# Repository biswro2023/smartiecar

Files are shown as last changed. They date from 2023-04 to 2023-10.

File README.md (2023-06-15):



Future Engineers - Smart Riders 
====

## Inhalt

* Der Ordner [`Programmcode`](https://github.com/biswro2023/smartiecar/tree/master/Programmcode) enthält den kompletten Programmcode, der für das Roboterauto verwendet wird.
* Im Ordner [`Roboterauto`](https://github.com/biswro2023/smartiecar/tree/master/Roboterauto) befinden sich sechs Fotos Von unserem Roboterauto aus allen Perspektiven
* Im Ordner [`Technische Zeichnungen`](https://github.com/biswro2023/smartiecar/tree/master/Technische%20Zeichnungen) sind Zeichnungen von Komponenten des Roboterautos oder dem gesamten Roboterauto abgelegt.
* Der Ordner [`Video`](https://github.com/biswro2023/smartiecar/blob/master/Video/video.md) beinhaltet die Datei "video.md", die mit zwei Links zu den Youtube-Videos weiterleitet. Das Video zeigt das Roboterauto beim Absolvieren des Spielfeldes in beiden Rennen.
* Der Ordner [`Unser Team`](https://github.com/biswro2023/smartiecar/tree/master/Unser%20Team) hat ein Bild von unserem Team zu Beginn und ein aktuelles sowie eine kurze Beschreibung über uns.

## Einleitung

Nach dem Ende unseres vorherigen FLL Wettbewerbes wollten wir erneut an einem Projekt arbeiten. Wir haben uns dazu entschieden in der WRO mitzuspielen und uns die verschiedenen Kategorien angeschaut. Ein anderes Team an unserer Schule hatte bereits an einem Future Engineers Projekt gearbeitet. Das hat uns sehr interessiert und wir haben uns entschieden ebenfalls in dieser Kategorie zu spielen. Selbstfahrende Autos sind generell schon ein sehr interessantes und aktuelles Thema, das in der heutigen Zeit immer wichtiger wird. Zu Beginn hörten sich die Aufgaben, wie Runden auf einer Matte zu fahren, deutlich leichter an, als sie tatsäclich waren. Schwierigkeiten machten oft Kleinigkeiten, wie Messungenauigkeiten oder dreckige Reifen.
Im Laufe der Zeit haben wir viel Arbeit in die Fehlervermeidung und Vorbeugung gesteckt. Wir haben viele Sicherheitsmechanismen eigebaut, bis das Auto in fast allen Situationen gut gefahren ist. Insgesamt aben wir jetzt deutlich besser verstanden, wie schwer die Entwicklung und Produktion von selbstfahrenden Autos eigentlich ist.

Details zum Entwicklungsprozess von Chassis und Elektronik des Autos Beschreiben wir in => [`RoboterAuto-Readme.md`](https://github.com/biswro2023/smartiecar/blob/master/Roboterauto/README.md)

Das Programm und Informationen zur Steuerlogik befinden sich in => [`Programmcode`](https://github.com/biswro2023/smartiecar/tree/master/Programmcode)

Unser Auto in Aktion ist zu sehen in =>  [`Video-Readme.md`](https://github.com/biswro2023/smartiecar/blob/master/Video/video.md)

Kino Shot

Quellen:

https://totemmaker.net/  (Auto/Rahmen)

https://de.wikipedia.org/wiki/Lenkung#Achsschenkellenkung    (Lenkgeometrie)

https://funduino.de/  (Programmierbeispiele etc.)

https://fritzing.org/   (Schaltpläne)

Coaching mit Team Leoneers 

https://www.arduino.cc/    (Programm etc.)

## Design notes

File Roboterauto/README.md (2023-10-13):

Roboterauto
====

Prozess:

Wir haben uns für die Konstruktion des Autos für das Totem Maker Bausystem (siehe Quellen) entschieden. Das Auto, dass auf der Website vorgeschlagen ist, ist zu groß und hat einen nicht erlaubten Antrieb. Deswegen haben wir unser Chassis neu konstruiert und nur teilweise auf die Anleitung zurückgegriffen.
Zu Beginn haben wir die ersten Schritte, der im Totem Maker Bausystem vorgeschlagenem Bauanleitung befolgt, um eine stabile Vorderachse zu erhalten.
Da das Auto, das die Anleitung beschreibt zu breit ist, mussten wir die Vorderachse kürzen. So überschreitet unser Auto die vorgegebenen Maße nicht.




Die Vorderachse beinhalted 3D gedruckte Teile, die jedoch von Totem Maker gedruckt und beigelegt wurden.
Die 3D gedruckten Teile, der Vorderachse stammen aus der STL-Libary von Totem Maker.
Zu dem Zeitpunkt haben wir die standard Reifen des Totem Maker Bausystems verwendet. 
Danach haben wir eine Bodenplatte aus 4mm dickem Kunststoff geschnitten und an die Vorderachse geschraubt.
Wir haben eine 4mm Platte genommen, da wir vermuteten, dass eine Platte, die nur 2mm dick ist, schnell brechen würde.
Um die Position der Hinterachse zu bestimmen haben wir mit Hilfe einer Bauzeichnung  unserer Bodenplatte ein Lenkdreieck gezeichnet.

Bodenplatte-1

Die Hinterachse und den Motor haben wir dann auf die Bodenplatte geschraubt.
Der Motor ist mit einer 1:1 Überetzung mit zwei Zahnrädern an der Hinterachse angeschlossen.
Anschließend haben wir uns überlegt und ausprobiert, wie wir die elektronischen Bauteile auf dem Auto befestigen. 
Der Motorkontroller so wie unseren Hauptstromschalter haben wir auch auf der Bodenplatte befestigt. 
Der Lipo-Akku liegt auf dem Rahmen unseres Autos.

Bei den ersten Testfahrten ist uns aufgefallen, dass unsere Reifen, die wir aus dem Totem Maker Bausystem genommen haben, zu groß sind und am 
Rahmen schleifen. Die zweiten Reifen aus dem Funduino Bauset waren kleiner und härter, aber sie übersteuerten oft wenn das Auto zu sehr einlenk.
Das Problem war dadurch teilweise gelöst.
Jetzt und Final verwenden wir Reifen, die weicher sind und kein Profil besitzen, wodurch der Bodenkontakt maximiert wird.
Diese Reifen haben wir aus einem Modellbauladen erhalten.

image0 (1)

Damit wir den Arduino auf dem Auto befestigen können, haben wir zuerst eine vorgeschnitte Kunststoffplatte aus dem Funduino Bauset benutzt. 
Diese ist aber leider gebrochen, weshalb wir eine neue Platte aus enem dickerem Kunststoff schneiden mussten.
Der Aurduino ist nun mit Kunststoff Abständen an dieser Platte fest geschraubt.

Links

Als der Ardunio befestigt war konnten wir schließlich Programme für das Auto schreiben und ausprobieren.
Um auch Feedback zu Problemen oder Erfolgen zu erhalten, haben wir ein LCD-Monitor auf dem Auto befestigt.
Dieser Monitor gibt sowohl am Anfang des Programmes Informationen über die Sensoren als Text, als auch durch den verschieden farbigen Hintergrund Informationen über den Aktuellen Status des Programmes.

Als wir den Monitor zum erstem mal angeschlossen hatten, konten wir nichts erkennen. der Monitor zeigte kein Text oder Farbe.
Wir fanden herraus, dass der Monitor 5 Volt benötigt, wir ihn aber nur 4.7 Volt angeschlossen hatten.
Deshalb haben wir sowohl für die Stromversorgung des LCD-Monitors als auch für die Stromversorgungs unseres Lenkservos eine extra Stromversorgungsleiste eingebaut

237098416-ef6eb164-e023-4361-834d-cc200a337ebe

Oben auf unserem Auto haben wir neben dem LCD-Monitor und der Stromleiste außerdem auch noch den Button für den Start und den Gyro für die Kurven montiert.
Zu Beginn hatten wir einen anderen größeren Button verwendet. Weil der jedoch einen großen Wiederstandhatte, der das Auto beim drücken mit nach unten drückte, und weil er nicht gut erreichbar montiert war,
haben wir den Button ausgetauscht zu dem Button, den wir jetzt verwenden.
Anschließend haben wir uns um das Kabelmanagement gekümmert. Wir haben die wichtigen Anschlüsse des Hauptsromsystems an der Außenseite mit schnell verschlüssen befestigt, da mit wir das Auto schnell warten 
und reparieren können.

Bild SV

Damit wir die Kurven gut fahren können haben wir außerdem neben dem Button ein Gyroskop eingebaut.
Das Gyroskop hilft uns genaue Kurven mit immer gleich bleibendem Winkel zu fahren.
Für das Hindernissrennen wollten wir anschließend auch eine Kamera an unserem Auto montieren.
Wir hatten zwei verschiedene Kameras zu auswahl: Die HHUSKYLENS und die PIXY CAM 2.

image0 (1)

Wir haben beide Kameras ausprobiert und sind schließlich bei der PIXY CAM geblieben.
Obwohl die HHUSKYLENS die Hindernisse und Linien gut erkennen konnte, hat die PIXY CAM ein größeres Blickfeld und mehr kofiguratiosns Möglichkeiten in dem zugehörigem Programm. Dadurch können wir viel mehr abstimmen und Feintuning betreiben.

Für die Energeiversorgung, die wir uns schon zu Beginn zurechtgelegt haben, benutzen wir eine 11,5 Volt Lipo Batterie.
Die Batterie gibt zwischen 9,4 und 12,4 Volt aus. Da der Motor 12 Volt benötigt und der zugehörige Motortreiber gleichzeitig auch noch 1,4 Volt bezieht, haben wir einen Step Up Converter einegbaut, der die Spannung auf 13.4 Volt erhöht.
So erhält der Motor immer die richtige Spannung. Da die eine Hälfte des Stroms zu dem Motor geleitet wird, wird die andere Hälfte zu einem Step Down Converter geleitet. Dieser reduziert die Spannung auf 5 Volt. Das ist wichtig, weil der Arduino nicht mit dem 13,4 Volt umgehen kann.
Diese 5 Volt leiten wir anschließend in einen USB-Hub der gleichzeitig auch als Voltmeter dient.
Aus diesem USB-Hub geht eine Stromleitung dierekt zu dem Arduino und die andere zur Hauptstromleiste. Diese mussten wir installieren, weil 
die 5 Volt ausgabe des Arduinos nicht genau 5 Volt ausgibt. Sowohl der LCD Monitor als auch der Lenkservo benötigen nämlich mindestens 5 Volt.

238084341-53173d58-f437-4e53-b33c-3225937c58c4

Nach dem ersten Wettbewerb in Chemitzt haben wir beschlossen die Halterung für die Kamera und die Ultraschallsensoren umzubauen.
Die alte Halterung hat sich schnell gelöst und verschoben. Nun ist die neu Halterung fest an den Rahmen des Autos befestigt.



Außerde haben wir für die Ultraschallsensoren neue Halterungen verwendet, damit sie stabiler sitzten und einfacher zu montieren sind.
Durch diese neuen Halterungen der Sensoren, waren diese jedoch leicht nach oben geneigt, was manchmal zu fehlmessungen führte.
Deshalb haben wir Kabelbinder verwendet, um die Sensoren zusammen zu binden und unten zu halten.
Da der Farbsensor, den wir zuvor an unserem Auto befestigt hatten die Farben des Spielfeldes immer wieder falsch erkannte,
haben wir uns dafür entschieden diesen zu entfernen, da er so keien Nutzen für uns hat.

Zusätzlich haben wir versucht ein neues Getriebe in das Auto einzubauen (zuvor 1:1). Wir wollten eine größere Übersetzung der Zahnräder dazu verwenden
unser Auto langsam fahren zu lassen, ohne, dass es stecken bleibt. Den zuvor konnten wir dies nur verhindern, indem wir schneller fuhren,
was das ganze Rennen ungenauer machte.Schließlich hat aber das neue Getriebe mehr neue Probleme hervorgebracht als alte gelöst.



Während der vielen Testrunden die wir gefahren sind ist neben Sensoren und Arduinos auch unser Lenkserveo einmal kaputt gegangen.
Die Kontruktionsweise des Autos behinderte den Austausch etwas, jedoch haben wir die Gelegenheit genutz gleichzeitig auch noch Teile Auszutauschen, an
die man sonst nicht so leicht dran kommt.



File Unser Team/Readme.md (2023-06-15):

Team Beschreibung
===
Unser Team besteht aus drei Jungs: Noah, Nezar und Lucius. Gemeinsam repräsentieren wir stolz die GSG Lünen und haben uns den Teamnamen "Smart Riders" gegeben. Wir gehen alle in die 10. Klasse, und es ist das erste Mal, dass wir an der WRO teilnehmen. Unser erstes Roboterprojekt war die Teilnahme an der FLL.

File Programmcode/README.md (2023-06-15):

Programmcode
====

Dieser Ordner enthält sämtlichen Programmcode, der in dem Roboterauto zum Einsatz kommt.
Zudem auch Programme zum testen ob diverse sensoren funktionieren. Zudem Backup Codes Im Fall von einer Änderung.

· [`Eröffnungsrennen`](https://github.com/biswro2023/smartiecar/tree/master/Programmcode/main_hinderniss_V01)

· [`Hindernissrennen`](https://github.com/biswro2023/smartiecar/tree/master/Programmcode/main_hinderniss_V01)

· [`Testprogramme`](https://github.com/biswro2023/smartiecar/tree/master/Programmcode/Test%20Programme)

· [`backup codes`](https://github.com/biswro2023/smartiecar/tree/master/Programmcode/alte_versionen/backup%20codes)

Allgemeines
===
Zuerst haben wir kleine kleine Testprogramme für die Bewegungen und Sensoren des Autos geschrieben. Dabei Haben wir uns an Beispielen von Funduino.de orientiert und Beispielprogramme der Sensorhersteller benutzt. Unsere neu geschriebenen Programme haben wir mit einer Versionsnummer im Namen gekennzeichnet. Zum Beispiel heisst die erste Version `main_OH_V1.ino`. Unsere Hauptdatei endet mit `.ino` und die untergeteilten Dateien mit `.h` 

Programmaufbau
===
Als erstes haben wir alle erforderlichen Bibliotheken für den Roboter und die einzelnen Komponenten hinzugefügt. Anschließend haben wir globale Variablen sowie unsere eigenen Variablen definiert. Eine der wichtigsten Aspekte unseres Programms sind die selbst erstellten Funktionen. Diese sind entscheidend, um den gesamten Ablauf des Rennens sowohl in der Schleife (Loop) als auch im Setup zu steuern. Es ist erwähnenswert, dass durch die selbstgeschriebenen Funktionen Änderungen leicht vorgenommen werden konnten, falls ein Fehler auftrat. Das gesamte Programm wurde in einzelne Module aufgeteilt, um einen besseren Überblick über die verschiedenen Funktionen zu haben. Zum Beispiel werden Funktionen wie `Kamera_Start()` in einer `cam.h`-Datei abgelegt, um den Zustand der Funktionen zu überprüfen. Es gibt unsere eigenen Funktionen sowie Funktionen für die PixyCam oder die IMU, die wir mithilfe von Testprogrammen übernommen haben.

Im Setup werden mithilfe unserer eigenen Funktionen alle wichtigen Komponenten wie der Ultraschallsensor gestartet. Die Ergebnisse werden dann auf dem LCD-Bildschirm angezeigt, um festzustellen, ob die Sensoren irgendwelche Probleme aufweisen. In der Schleife (Loop) werden verschiedene Funktionen aufgerufen, um die Blöcke mithilfe der PixyCam zu erkennen und sie vor dem Fahren auf dem LCD-Bildschirm anzuzeigen, um letztendlich einen fehlerfreien Start zu gewährleisten. Schließlich werden die Kurvenberechnungen durchgeführt, um gezielte Runden zu fahren. Die Funktionen sind mit kurzen Sätzen beschrieben, die als Beschreibung dienen.

Eröffnungsrennen
===
1. `SpaceUS_L()` und `SpaceUS_R()` messen den Abstand des Fahrzeugs zur linken bzw. rechten Seite der Kurve.
2. Die Funktion `IMU_getAngle()` aktualisiert die Orientierung des Fahrzeugs.
2a. Wenn das Auto direkt neben einer Wand startet, kann die FR sofort als Abstand zur Wand < 10 cm bestimmt werden.
3. Das Programm bestimmt die Fahrtrichtung anhand der gemessenen Abstände zur Kurve. Ansonsten bestimmt das Programm die FR, sobald die Abstandssensoren auf einer Seite keine Wand mehr erkennen können.
4. Wenn das Fahrzeug geradeaus fährt, die Fahrtrichtung noch nicht bekannt ist `(FR == K)` und der Abstand zur linken Seite der Kurve größer als 60 ist, ändert das Programm die Fahrtrichtung auf links `(FR = 'L')`. Das Gleiche gilt auch für rechts.
5. Zunächst fährt das Fahrzeug geradeaus. Wenn der Abstand zur rechten Wand größer als 60 ist und die FR rechtsrum ist, fährt der Bot eine Rechtskurve `Kurve_R()`.
5a. Das Gleiche gilt auch für links: `Kurve_L()`.
5b. Nach jeder Kurve wird die Anzahl der Ecken um eins erhöht und gespeichert.
6. Wenn das Fahrzeug nach links fahren soll und der Abstand zur linken Seite der Kurve größer als 60 ist, führt das Programm die `Kurve_L()` Funktion aus.
7. Wenn das Fahrzeug nach rechts fahren soll und der Abstand zur rechten Seite der Kurve größer als 60 ist, führt das Programm die `Kurve_R()` Funktion aus.
8. Die Funktion `Ausrichten()` sorgt dafür, dass das Fahrzeug in die richtige Ausrichtung gebracht wird, indem es versucht, das Auto in die Mitte zu steuern, basierend auf den gemessenen Seitenabständen.
8a. Sobald `FR` bekannt ist, orientiert sich der Roboter an der Innenbande mit einem festen Abstand von 25 cm. Dafür haben wir die Funktionen `Ausrichten_L()` und `Ausrichten_R()`.
9. Wenn der Abstand zur Kurve kleiner als 80 cm ist, fährt das Fahrzeug langsamer.
10. Wenn das Auto 12 Ecken gefahren ist und diese gezählt hat, fährt es noch ein Stück geradeaus und bleibt im geraden Abschnitt stehen.

Diagramm_Eröffnung
#

Hindernissrennen
===
1. Zuerst wird auf Hindernisse geprüft mit der `Finde_Block()` Funktion.
2. Der Abstand nach vorne wird mit `SpaceUS_V()` gemessen.
3. Auf dem LCD werden dann die gefundenen Blöcke angezeigt.
3a. Je nach `BlockID` wird mit `lcd.setRGB()` die Farbe gesetzt. Wenn kein Block in Sicht ist, wird der Bildschirm weiß gesetzt.
4. Die Pixy prüft, ob der gesehene Block im richtigen Bereich steht. Zudem wird überprüft, ob der Block zu nah ist. Wenn ja, setzt sich der Roboter zurück durch Rückwärtsfahren.
4a. Wenn es keine Probleme gibt, führt er die Funktion `Ausweichen_R()` aus.
5. Das Gleiche gilt für den grünen Block.
6. Im Fall, dass kein Block in Sicht ist, der ausgewichen werden muss, messen alle Sensoren noch einmal die Abstände aus allen Seiten.
6a. Wenn der `Abstand_R()` zur Außenwand kleiner als 80 cm beträgt, wird `FR` auf Rechts gesetzt. Für links auch mit der Funktion `Abstand_L()`.
7. Anschließend wird wieder auf eine Kurve oder Wende geprüft.
8. Wenn kein Hindernis erkannt wurde, wird eine Notbremse mit der Funktion `runMotor_R()` gezogen.
9. Am Ende orientiert er sich wieder an der Außenwand, indem `Abstand_R()` und `Abstand_L()` gleich `SpaceUS_L()` und `SpaceUS_R()` gesetzt werden.
10. Sollte es trotzdem dazu kommen, dass der Roboter kein Hindernis erkennt, "würfelt" er sich eine Antwort mit einem Zufallsgenerator mit der Variable `int zufall`.

Diagramm_Hindernisse

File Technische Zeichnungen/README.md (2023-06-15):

Technische Zeichnungen
====

Dieser Ordner enthält:

eine pdf Datei der Bodenplatte unseres Roboters,

sowie eine Bild Datei mit dem aktuellsten Schaltplan

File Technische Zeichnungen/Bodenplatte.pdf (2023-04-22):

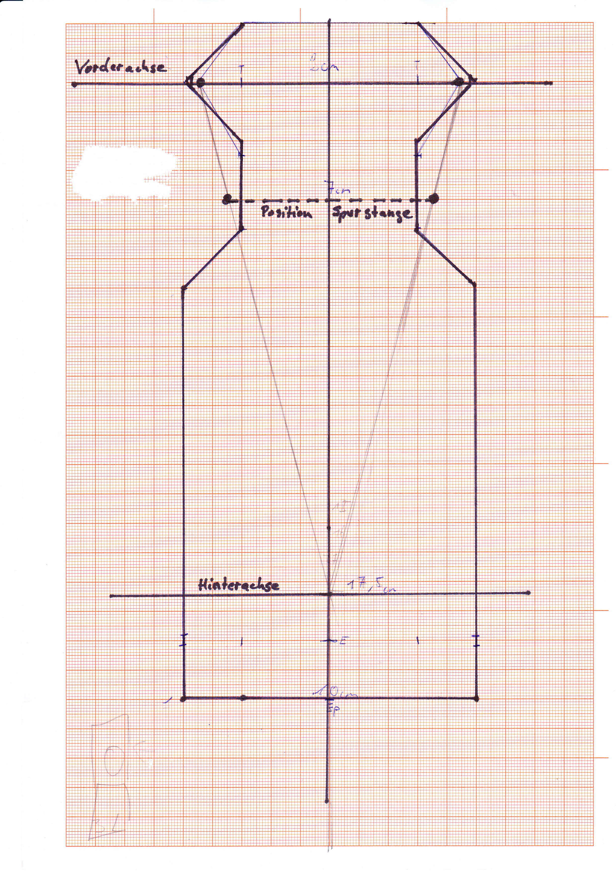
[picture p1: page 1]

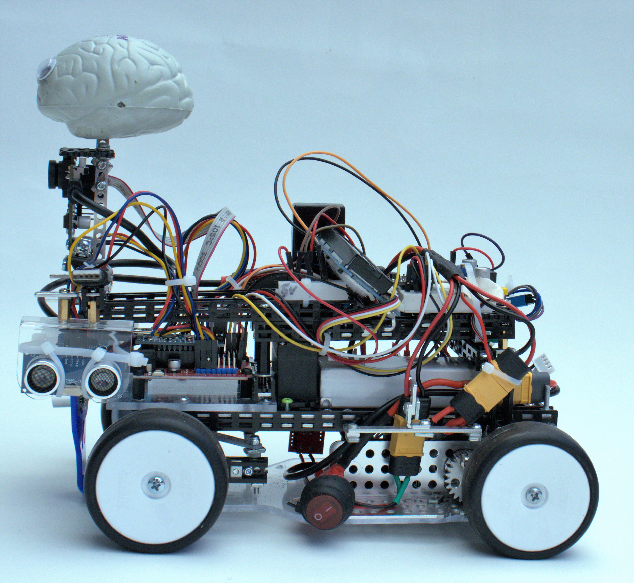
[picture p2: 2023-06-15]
Roboterauto/Links.jpg

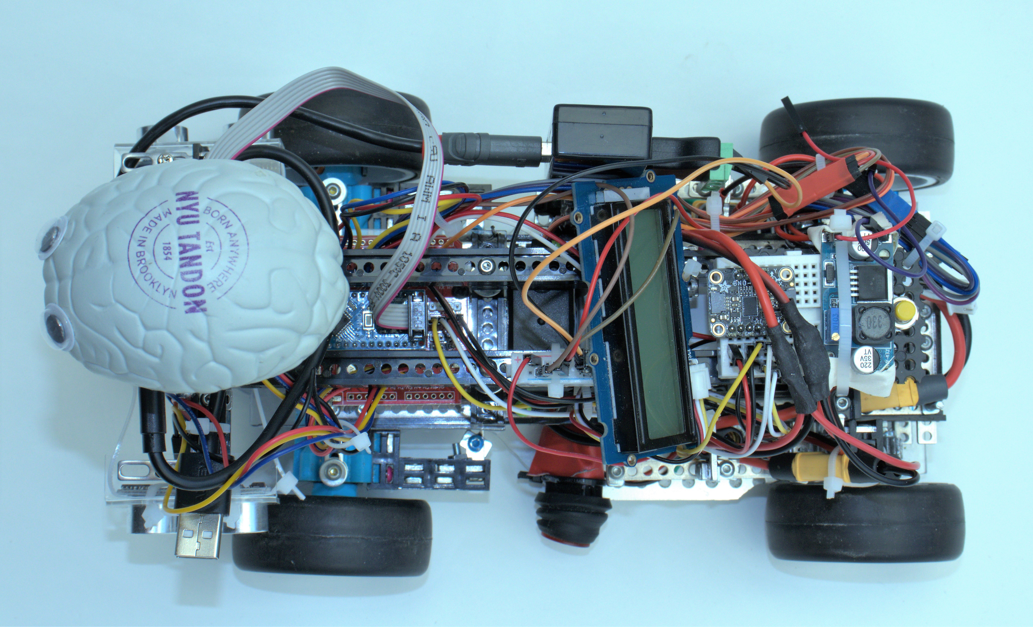
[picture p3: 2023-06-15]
Roboterauto/Oben.jpg

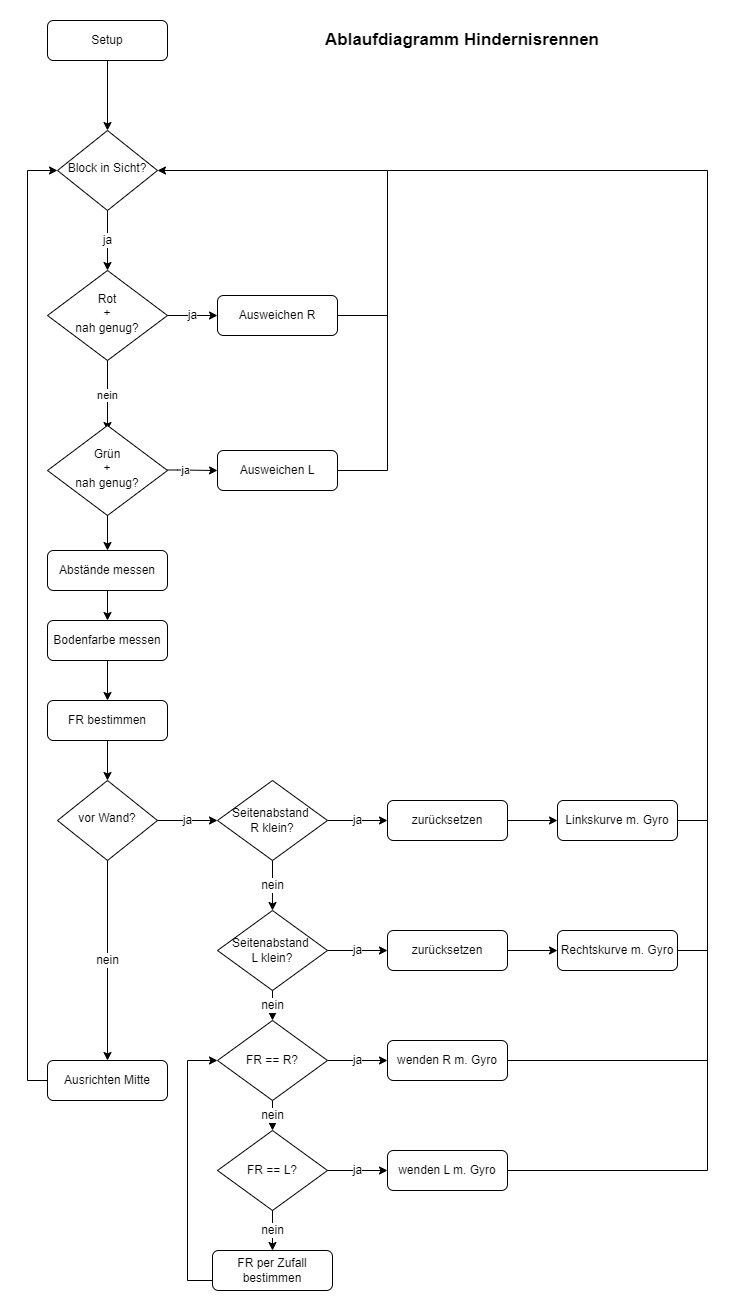
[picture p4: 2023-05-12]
Programmcode/Diagramm_Hindernisse.jpg

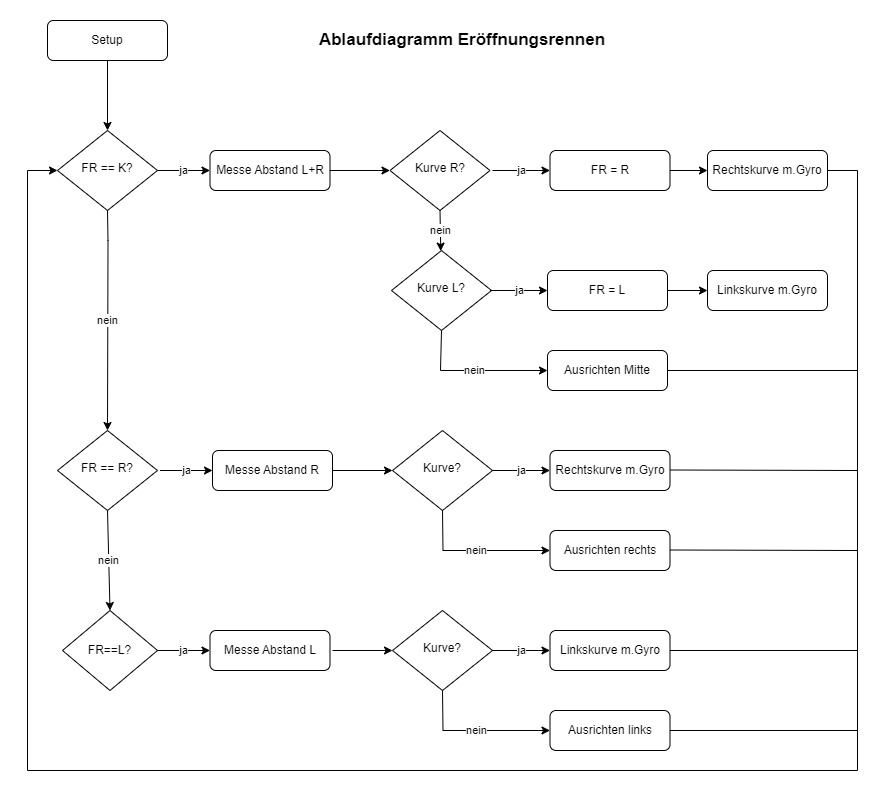
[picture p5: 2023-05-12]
Programmcode/Diagramm_Eröffnung.jpg

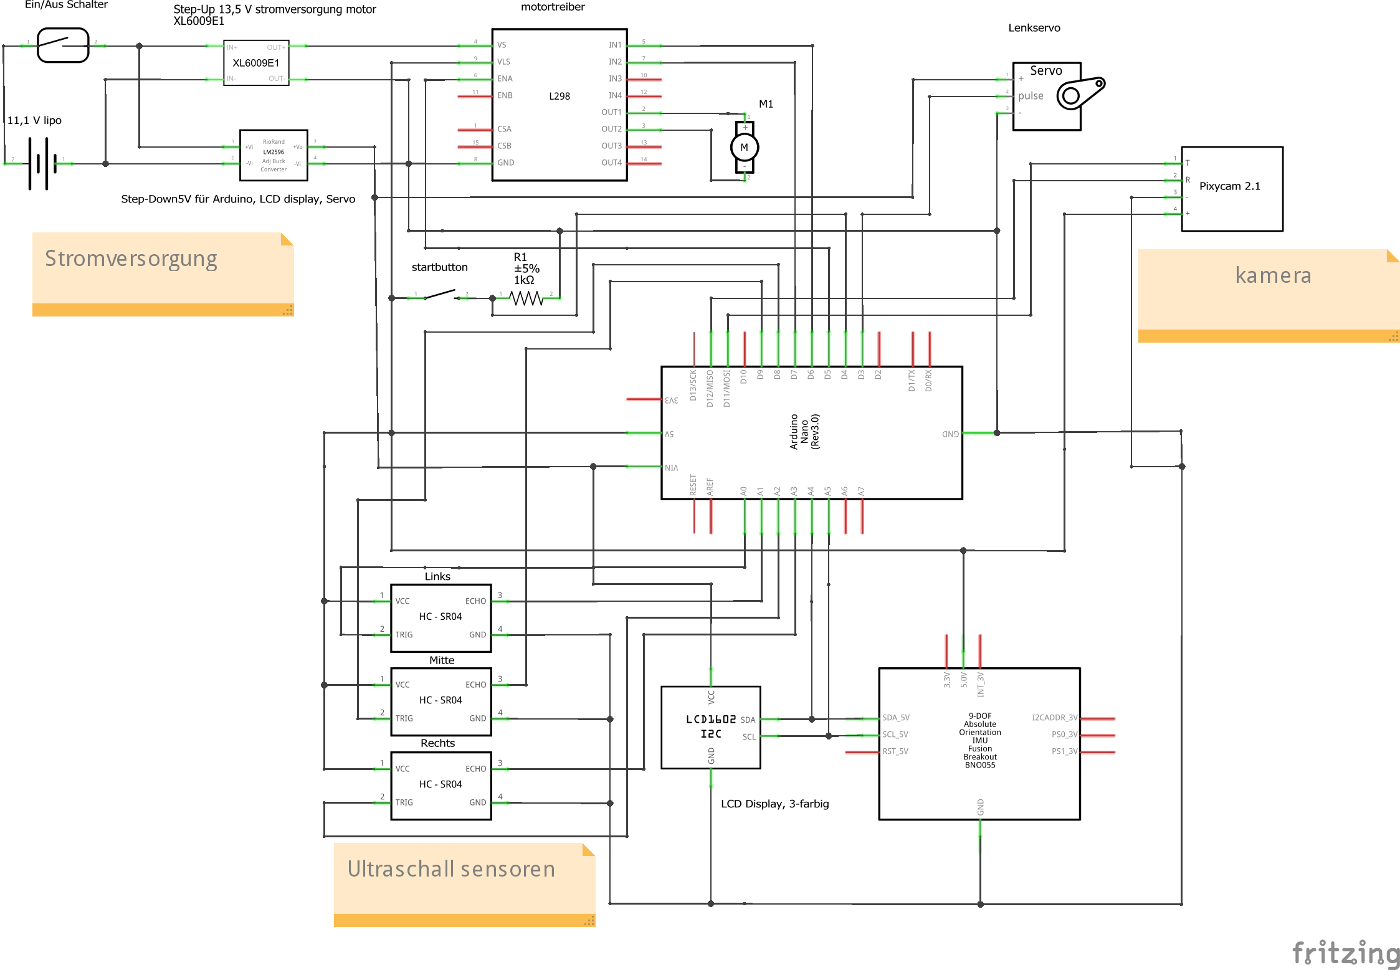
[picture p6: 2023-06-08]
Technische Zeichnungen/Schaltplan smart riders_mit_Kamera_OF.png

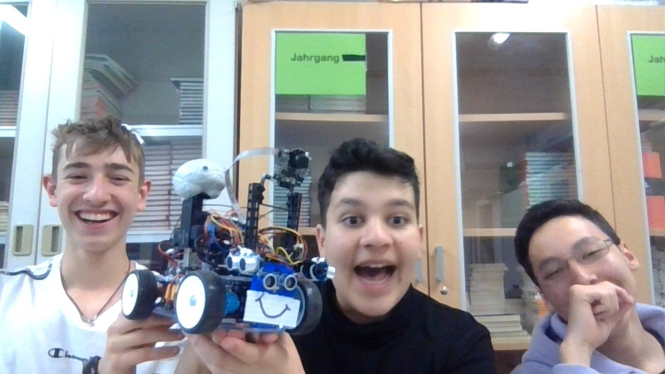
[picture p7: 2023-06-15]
Unser Team/Arduino version 0.1.jpg

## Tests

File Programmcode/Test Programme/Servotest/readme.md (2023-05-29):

# Sweep

Sweeps the shaft of a RC [servo motor](http://en.wikipedia.org/wiki/Servo_motor#RC_servos) back and forth across 180 degrees.

## Hardware Required

* Arduino Board
* Servo Motor
* Hook-up wires

## Circuit

Servo motors have three wires: power, ground, and signal. The power wire is typically red, and should be connected to the 5V pin on the Arduino board. The ground wire is typically black or brown and should be connected to a ground pin on the board. The signal pin is typically yellow, orange or white and should be connected to pin 9 on the board.



(Images developed using Fritzing. For more circuit examples, see the [Fritzing project page](http://fritzing.org/projects/))

## Schematic



## See also

* [attach()](/docs/api.md#attach)
* [write()](/docs/api.md#write)
* [map()](https://www.arduino.cc/en/Reference/Map)
* [Servo library reference](/docs/readme.md)
* [Knob](../Knob) - Control the position of a servo with a potentiometer

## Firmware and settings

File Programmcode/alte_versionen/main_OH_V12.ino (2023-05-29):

//hauptprogramm mit Hindernissen V12

//Belegung der Pins
//button = 4
//kamera = 10-13
//Ultraschall = 5-6
//I2C Bus = A4-A5 -> LCD, Gyro, Farbsensor
//MotorSpeed = 9
//Motorichtung = 7-8
//Abstandsmesser (Lox's) = A0-A1
//Servo Lenkung = 3
//frei = A2-A3

///////////////////////////////////////////////////////////////
/*

██╗     ██╗██████╗ ██████╗  █████╗ ██████╗ ██╗███████╗███████╗
██║     ██║██╔══██╗██╔══██╗██╔══██╗██╔══██╗██║██╔════╝██╔════╝
██║     ██║██████╔╝██████╔╝███████║██████╔╝██║█████╗  ███████╗
██║     ██║██╔══██╗██╔══██╗██╔══██║██╔══██╗██║██╔══╝  ╚════██║
███████╗██║██████╔╝██║  ██║██║  ██║██║  ██║██║███████╗███████║
╚══════╝╚═╝╚═════╝ ╚═╝  ╚═╝╚═╝  ╚═╝╚═╝  ╚═╝╚═╝╚══════╝╚══════╝
                                                              
*/
///////////////////////////////////////////////////////////////


//Servo Abteilung libraries
#include <Servo.h>
//-------------------------------------------------

//libraries rgb
#include <Wire.h>
#include "rgb_lcd.h"

//--------------------------------------------------

//gyro
#include <MPU6050_light.h>
#include <Adafruit_Sensor.h>
#include <Adafruit_BNO055.h>
#include <utility/imumaths.h>
#define BNO055_SAMPLERATE_DELAY_MS (10)
//---------------------------------------------------

//Farbsensor
#include "Adafruit_TCS34725.h"

// Pixy2 Cam
#include "Pixy2.h"


/////////////////////////////////////////////////////////////////////////////////////////////////////////////////////////////////////
/*       
██████╗ ██╗      ██████╗ ██████╗  █████╗ ██╗     ███████╗    ██╗   ██╗ █████╗ ██████╗ ██╗ █████╗ ██████╗ ██╗     ███████╗███╗   ██╗
██╔════╝ ██║     ██╔═══██╗██╔══██╗██╔══██╗██║     ██╔════╝    ██║   ██║██╔══██╗██╔══██╗██║██╔══██╗██╔══██╗██║     ██╔════╝████╗  ██║
██║  ███╗██║     ██║   ██║██████╔╝███████║██║     █████╗      ██║   ██║███████║██████╔╝██║███████║██████╔╝██║     █████╗  ██╔██╗ ██║
██║   ██║██║     ██║   ██║██╔══██╗██╔══██║██║     ██╔══╝      ╚██╗ ██╔╝██╔══██║██╔══██╗██║██╔══██║██╔══██╗██║     ██╔══╝  ██║╚██╗██║
╚██████╔╝███████╗╚██████╔╝██████╔╝██║  ██║███████╗███████╗     ╚████╔╝ ██║  ██║██║  ██║██║██║  ██║██████╔╝███████╗███████╗██║ ╚████║
 ╚═════╝ ╚══════╝ ╚═════╝ ╚═════╝ ╚═╝  ╚═╝╚══════╝╚══════╝      ╚═══╝  ╚═╝  ╚═╝╚═╝  ╚═╝╚═╝╚═╝  ╚═╝╚═════╝ ╚══════╝╚══════╝╚═╝  ╚═══╝
*/                                                                                                                               
/////////////////////////////////////////////////////////////////////////////////////////////////////////////////////////////////////

 Pixy2 pixy;
 int Bildmitte_x = 157;
 int Bildmitte_y = 104;



//Farbsensor
Adafruit_TCS34725 tcs = Adafruit_TCS34725(TCS34725_INTEGRATIONTIME_50MS, TCS34725_GAIN_4X);
uint16_t white, red, green, blue, white_ref;
int bodenfarbe = 0;

//gyro
//(AUSKOMMENTIERT) MPU6050 mpu(Wire);
Adafruit_BNO055 bno = Adafruit_BNO055(55, 0x28, &Wire);
sensors_event_t event;

//servo pin
int Servopin = 3;
int mittig = 135;
// Erstelle ein Servo-Objekt
Servo servo;
//timer
unsigned long start_time;
//--------------------------------------------------

//Ultraschall abteil

// Definition der pins

//Vorderer sensor
#define TRIG_PIN_V  8
#define ECHO_PIN_V  9
#define BAUD_RATE  9600

//Linker Sensor
#define TRIG_PIN_L  A0
#define ECHO_PIN_L  A1

//Rechter Sensor
#define TRIG_PIN_R  A2
#define ECHO_PIN_R  A3


// Gleichstrommotor 1
int GSM1 = 5;
int in1 = 6;
int in2 = 7; 

//LCD anschluss
 int Button = 4;
 int colorR = 255;
 int colorG = 0;
 int colorB = 0;
 //LCD screen selbst
 rgb_lcd lcd;

//runden/ecken zähler
int ecken = 0;
int runden = 0; 
int quadrant = 0;

//Abstands eigene  funktionen (messwerte)
 int Abstand;
 int Abstand_L;
 int Abstand_R;
 
 float winkel;
 float gefahr;
 float korrektur_L = -15.0;
 float korrektur_R = 15.0;
 
  //Fahrtrichtung
  char FR = 'K';

 //geschwindigkeiten
  int NormG = 180;
  int LangG = 160;
  int KurvG = 200; 

  //hindernisse
  char Block = 'K';


 //Block
 int B_ID = 0;
 int B_x = 0;
 int B_y = 0;
 int B_hoch = 0;
 int B_breit = 0;
 int B_Unterkante = 0;
 int B_Abstand = 0;

 //letzte kurve messen
 unsigned long MKurve;
 unsigned long ZKurve = 3000;
  
  //beide ausrichtungen (L/R)
  int Wandabstand = 40;

////////////////////////////////////////////////////////////////////////////////////////////////////////////////////////////////////////
/*
    
███████╗██╗ ██████╗ ███████╗███╗   ██╗███████╗    ███████╗██╗   ██╗███╗   ██╗██╗  ██╗████████╗██╗ ██████╗ ███╗   ██╗███████╗███╗   ██╗
██╔════╝██║██╔════╝ ██╔════╝████╗  ██║██╔════╝    ██╔════╝██║   ██║████╗  ██║██║ ██╔╝╚══██╔══╝██║██╔═══██╗████╗  ██║██╔════╝████╗  ██║
█████╗  ██║██║  ███╗█████╗  ██╔██╗ ██║█████╗      █████╗  ██║   ██║██╔██╗ ██║█████╔╝    ██║   ██║██║   ██║██╔██╗ ██║█████╗  ██╔██╗ ██║
██╔══╝  ██║██║   ██║██╔══╝  ██║╚██╗██║██╔══╝      ██╔══╝  ██║   ██║██║╚██╗██║██╔═██╗    ██║   ██║██║   ██║██║╚██╗██║██╔══╝  ██║╚██╗██║
███████╗██║╚██████╔╝███████╗██║ ╚████║███████╗    ██║     ╚██████╔╝██║ ╚████║██║  ██╗   ██║   ██║╚██████╔╝██║ ╚████║███████╗██║ ╚████║
╚══════╝╚═╝ ╚═════╝ ╚══════╝╚═╝  ╚═══╝╚══════╝    ╚═╝      ╚═════╝ ╚═╝  ╚═══╝╚═╝  ╚═╝   ╚═╝   ╚═╝ ╚═════╝ ╚═╝  ╚═══╝╚══════╝╚═╝  ╚═══╝
*/
/////////////////////////////////////////////////////////////////////////////////////////////////////////////////////////////////////////

//-------Fahren -----------------------------
 void runMotor(int Speed) {
  digitalWrite(in1, HIGH);  // Motor 1 beginnt zu rotieren
  digitalWrite(in2, LOW);
  analogWrite(GSM1, Speed);   // Motor 1 soll mit der Geschwindigkeit "200" (max. 255) rotieren
 }

 // Stoppen
 void stopMotor() {
  digitalWrite(in1, LOW);  
  digitalWrite(in2, LOW);
  analogWrite(GSM1, 0);  
 }

// rückwärts
 void runMotor_R(int Speed) {
  digitalWrite(in1, LOW);  
  digitalWrite(in2, HIGH);
  analogWrite(GSM1, Speed);  
 }

//Stop programm
void PRGstopp() {
  unsigned long FZ;  
    digitalWrite(in1, LOW);
    digitalWrite(in2, LOW);
    analogWrite(GSM1, 0);
  // Speichere die aktuelle Zeit
  FZ = millis() - start_time;
    lcd.clear();
    lcd.setCursor(0, 0);
    lcd.print("zeit: ");
    lcd.print(FZ);
    delay(9999999);

}

// wenden
 void wenden_L()
 {
    float ZW;
	  int Speed;
    lcd.setRGB(125,0,125);

    Speed = LangG;
     //rückwärts drehen
		 rechts(35);
		 runMotor_R(LangG);
        
        if(quadrant == 0)
        {
          ZW = 270.0;
        }
        else if(quadrant == 1)
        {
          ZW = 180.0;
        }
        else if(quadrant == 2)
        {
          ZW = 90.0;
        }
        else if(quadrant == 3)
        {
          ZW = 0.0;
        }
       winkel = IMU_getAngle();  
       Finde_Block();
       //Drehen, bis 90 Grad oder Block in Sicht             
        while((winkel > ZW - korrektur_L))
        {

           winkel = IMU_getAngle();
           Finde_Block();
            Speed = Speed + 5;
            if (Speed > KurvG)
            {
              Speed = KurvG;
            }
              runMotor_R(Speed);
              /*lcd.setCursor(0,0);
              lcd.print(winkel);*/
              delay(20);
        }
    stopMotor();
     mitte();
	 Abstand_L = SpaceUS_L();
   Abstand_R = SpaceUS_R();
   lcd.setRGB(255,255,255);
   MKurve = millis();
	 runMotor(LangG);
	 ecken = ecken + 1;
 }
 
  void wenden_R()
 {
    float ZW;
	  int Speed;
    lcd.setRGB(125,0,125);
    Speed = LangG;
     //rückwärts drehen
		 links(35);
		 runMotor_R(LangG);
         winkel = IMU_getAngle();
        if(quadrant == 0)
        {
          ZW = 90.0;
        }
        else if(quadrant == 1)
        {
          ZW = 180.0;
        }
        else if(quadrant == 2)
        {
          ZW = 270.0;
        }
        else if(quadrant == 3)
        {
          ZW = 360.0;
        }
        while(winkel < ZW - korrektur_R)
        {
           winkel = IMU_getAngle();

            Speed = Speed + 5;
            if (Speed > KurvG)
            {
              Speed = KurvG;
            }
              runMotor_R(Speed);
        }
     stopMotor();
      ecken = ecken + 1;
      mitte();
	  Abstand_L = SpaceUS_L();
    Abstand_R = SpaceUS_R();
    lcd.setRGB(255,255,255);
    MKurve = millis();
     runMotor(LangG);

 }
 
 
  //ausrichten
  void Ausrichten()
  {
    int Lenkung;
    Lenkung = (Abstand_L - Abstand_R)*0.3;

    if (Lenkung > 30.0)
    {
      Lenkung = 30;
    }
    else if (Lenkung < -30.0)
    {
      Lenkung = -30;
    }


    if(Lenkung < 0)
    {
      Lenkung = Lenkung *(-1);
      rechts(Lenkung);
    }
    
    else
    {
      links(Lenkung);
    }

  }

   //ausrichten
  void Ausrichten_L()
  {
    int Lenkung;
    Lenkung = (Abstand_L - Wandabstand)*0.8;
    if (Lenkung > 20.0)
    {
      Lenkung = 20;
    }
    else if (Lenkung < -20.0)
    {
      Lenkung = -20;
    }

    if(Lenkung < 0)
    {
      Lenkung = Lenkung *(-1);
      rechts(Lenkung);
    }
    
    else
    {
      links(Lenkung);
    }

  }

   //ausrichten
  void Ausrichten_R()
  {
    int Lenkung;
    Lenkung = (Wandabstand - Abstand_R)*0.8;
    if (Lenkung > 20.0)
    {
      Lenkung = 20;
    }
    else if (Lenkung < -20.0)
    {
      Lenkung = -30;
    }

    if(Lenkung < 0)
    {
      Lenkung = Lenkung *(-1);
      rechts(Lenkung);
    }
    
    else
    {
      links(Lenkung);
    }

  }

  void Kurve_L_MH()
  {
         int Speed;
         float ZW;
         Speed = LangG;
         lcd.setRGB(0, 0, 255);
        links(30);
    
        
        if(quadrant == 0)
        {
          ZW = 270.0;
        }
        else if(quadrant == 1)
        {
          ZW = 180.0;
        }
        else if(quadrant == 2)
        {
          ZW = 90.0;
        }
        else if(quadrant == 3)
        {
          ZW = 0.0;
        }
       winkel = IMU_getAngle();
       runMotor(LangG);  
       Finde_Block();
       //Drehen, bis 90 Grad oder Block in Sicht             
        while((winkel > ZW - korrektur_L) && (B_ID == 0))
        {

           winkel = IMU_getAngle();
           Finde_Block();
            Speed = Speed + 5;
            if (Speed > KurvG)
            {
              Speed = KurvG;
            }
              runMotor(Speed);
              /*lcd.setCursor(0,0);
              lcd.print(winkel);*/
              delay(20);
        }
        /*
        stopMotor();
        lcd.setCursor(0,0);
        lcd.print(B_ID);
        delay(1000);
        
        runMotor(LangG);
        // Drehe auf Block zu
        if (B_ID == 1) // rot
        {   lcd.setRGB(255,0,0);
            Zu_Rot();
        }
        else if (B_ID == 2)
        {   lcd.setRGB(0,255,0);
            Zu_Gruen();
        }
        */
        mitte();

     ecken = ecken + 1;
     
    runMotor(LangG);
    Abstand_L = SpaceUS_L;
    Abstand_R = SpaceUS_R;
    lcd.setRGB(255, 255, 255);
    MKurve = millis();
  }

void Zu_Rot()
{
   
   Finde_Block();
   if (B_x > Bildmitte_x - 10)
   {
      rechts(25);
      while (B_x > Bildmitte_x -10)
      {
        delay(20);
        Finde_Block();
      }
      
   }
   else if (B_x < Bildmitte_x)
   {
      links(25);
      while (B_x > Bildmitte_x -10)
      {
        delay(20);
        Finde_Block();
      }
   }
   mitte();
   Abstand = SpaceUS_V();
   while (Abstand > 30)
   {
     delay(50);
     Abstand = SpaceUS_V();
   }
}

void Zu_Gruen()
{
   
   Finde_Block();
   if (B_x > Bildmitte_x - 10)
   {
      links(25);
      while (B_x > Bildmitte_x -10)
      {
        delay(20);
        Finde_Block();
      }
      
   }
   else if (B_x < Bildmitte_x)
   {
      rechts(25);
      while (B_x > Bildmitte_x -10)
      {
        delay(20);
        Finde_Block();
      }
   }
   mitte();
   Abstand = SpaceUS_V();
   while (Abstand > 30)
   {
     delay(50);
     Abstand = SpaceUS_V();
   }

}

void Kurve_R_MH()
    {
         int Speed;
         float ZW;
         Speed = LangG;
         lcd.setRGB(0, 0, 255);
          rechts(30);
        winkel = IMU_getAngle();
        if(quadrant == 0)
        {
          ZW = 90.0;
        }
        else if(quadrant == 1)
        {
          ZW = 180.0;
        }
        else if(quadrant == 2)
        {
          ZW = 270.0;
        }
        else if(quadrant == 3)
        {
          ZW = 360.0;
        }
        while(winkel < ZW - korrektur_R)
        {
           winkel = IMU_getAngle();

            Speed = Speed + 5;
            if (Speed > KurvG)
            {
              Speed = KurvG;
            }
              runMotor(Speed);
        }

      ecken = ecken + 1;
      mitte();
    runMotor(LangG);
    Abstand_L = SpaceUS_L();
    Abstand_R = SpaceUS_R();
    lcd.setRGB(255, 255, 255);
    MKurve = millis();
  }


void Ausweichen_L()
{
  float winkel;
  float ZW;
  int Speed;

  //Zum Hindernis lenken, auf Hindernis zufahren, bei 20 cm Abstand stoppen
  if (B_x > Bildmitte_x)
  {
     
  }
  else if (B_x < Bildmitte_x)
  {

  }

  // Speichere Ausrichtung und Quadrant
  links(25);
  runMotor(KurvG);
  // Drehen, bis Block nicht mehr zu sehen
  while(B_ID == 2)
  {
    delay(20);
    Finde_Block();
  }
  runMotor(LangG);
  mitte();
  
  delay(40);    //geradeaus nach delay
  rechts(25);
  runMotor(KurvG);
  // Lenke auf gerade Ausrichtung nach Gyro
  ZW = IMU_ZW_gerade();
  winkel = IMU_getAngle();
  while(winkel < ZW )
  {
      winkel = IMU_getAngle();
      delay(20);
  }
  mitte();
  runMotor(LangG);
  // Vorbeifahren
  delay (200);
  lcd.setRGB(255,255,255);
  
}  



void Ausweichen_R()
{
  float winkel;
  float ZW;
  int Speed;

  //Zum Hindernis lenken, auf Hindernis zufahren, bei 20 cm Abstand stoppen
  if (B_x > Bildmitte_x)
  {
     
  }
  else if (B_x < Bildmitte_x)
  {

  }

  // Speichere Ausrichtung und Quadrant
  rechts(25);
  runMotor(KurvG);
  // Drehen, bis Block nicht mehr zu sehen
  while(B_ID == 1)
  {
    delay(20);
    Finde_Block();
  }
  runMotor(LangG);
  mitte();
  
  delay(20);    //geradeaus nach delay
  links(25);
  runMotor(KurvG);
  // Lenke auf gerade Ausrichtung nach Gyro
  if(quadrant == 0)
  {
    ZW = 360.0;
  }
  else if(quadrant == 1)
  {
    ZW = 90.0;
  }
  else if(quadrant == 2)
  {
    ZW = 180.0;
  }
  else if(quadrant == 3)
  {
    ZW = 270.0;
  }
  winkel = IMU_getAngle();
  while(winkel > ZW - korrektur_L)
  {
      winkel = IMU_getAngle();
      /*
      lcd.setCursor(0,0);
      lcd.print(winkel);
      lcd.print("   ");
      */
      delay(20);
  }
  mitte();
  runMotor(LangG);
  // Vorbeifahren
  delay (200);
  lcd.setRGB(255,255,255);
  
}  

//----------------------Farbsensor----------------------------------------
void Farb_Start()
{
  // Starte Farbsensor
  lcd.setCursor(0,0);
  if (tcs.begin()) 
  {
    lcd.print("Farbe ok  ");
  } 
  else 
  {
    lcd.print("Farbe ERR");
    while (1); // halt!
  }

  tcs.setInterrupt(false);      // LED an
  delay(60);

  // Speicher Helligkeit des Bodens = weiß
  tcs.getRawData(&red, &green, &blue, &white_ref);

}

int Bodenfarbe()
{
  int farbe = 0;
  tcs.getRawData(&red, &green, &blue, &white);
 
  // wenn Boden dunkler, Linie gefunden
  if (white < white_ref*0.8)
  {
    // am meisten rot -> orange Linie
    if ((red > blue) && (red > green))
    {
      farbe = 1;
    }
    // am meisten blau -> blaue Linie
    else if ((blue > red) && (blue > green))
    {
      farbe = 2;    
    }
    // sonst: k.A.
    else
    {
      farbe = 0;
    }
  }
  else
  {
     farbe = 0;
  }

  return farbe;

}

/////////////////////////////////////////////////////////////////////////////////////////////////////////////////////////////////////////
/*

██████╗ ██╗██╗  ██╗██╗   ██╗     ██████╗ █████╗ ███╗   ███╗███████╗██╗   ██╗███╗   ██╗ ██████╗████████╗██╗ ██████╗ ███╗   ██╗███████╗
██╔══██╗██║╚██╗██╔╝╚██╗ ██╔╝    ██╔════╝██╔══██╗████╗ ████║██╔════╝██║   ██║████╗  ██║██╔════╝╚══██╔══╝██║██╔═══██╗████╗  ██║██╔════╝
██████╔╝██║ ╚███╔╝  ╚████╔╝     ██║     ███████║██╔████╔██║█████╗  ██║   ██║██╔██╗ ██║██║        ██║   ██║██║   ██║██╔██╗ ██║███████╗
██╔═══╝ ██║ ██╔██╗   ╚██╔╝      ██║     ██╔══██║██║╚██╔╝██║██╔══╝  ██║   ██║██║╚██╗██║██║        ██║   ██║██║   ██║██║╚██╗██║╚════██║
██║     ██║██╔╝ ██╗   ██║       ╚██████╗██║  ██║██║ ╚═╝ ██║██║     ╚██████╔╝██║ ╚████║╚██████╗   ██║   ██║╚██████╔╝██║ ╚████║███████║
╚═╝     ╚═╝╚═╝  ╚═╝   ╚═╝        ╚═════╝╚═╝  ╚═╝╚═╝     ╚═╝╚═╝      ╚═════╝ ╚═╝  ╚═══╝ ╚═════╝   ╚═╝   ╚═╝ ╚═════╝ ╚═╝  ╚═══╝╚══════╝
*/
/////////////////////////////////////////////////////////////////////////////////////////////////////////////////////////////////////////                                                                                                                                   
void Kamera_Start()
{
  lcd.setCursor(0, 0);
  lcd.print(F("Pixy Start "));
  pixy.init();
  // Licht an
  pixy.setLamp(1,1);

  lcd.setCursor(0, 0);
  lcd.print(F("Cam OK     "));
  

}


void Finde_Block()
{
  
    int unterkante = 0;
    float tmp = 0.0;

    B_ID = 0;
    B_x = 0;
    B_y = 0;
    B_hoch = 0;
    B_breit = 0;
    B_Unterkante = 0;  
    B_Abstand = 0;  

  
    //pixy.ccc.getBlocks(false,3,2); // no wait, nur sign. 1+2, max. 2 Blocks
    pixy.ccc.getBlocks();

 //Finde nächsten Block (muss nicht der größte sein!)
    for (int i=0; i<pixy.ccc.numBlocks; i++)
    {
      // betrachte nur IDs 1 und 2
      if ((pixy.ccc.blocks[i].m_signature == 1) || (pixy.ccc.blocks[i].m_signature == 2))
      {

          unterkante = pixy.ccc.blocks[i].m_y + pixy.ccc.blocks[i].m_height/2;

          if (unterkante > B_Unterkante )
          {
            
            B_ID = pixy.ccc.blocks[i].m_signature;
            B_x = pixy.ccc.blocks[i].m_x;
            B_y = pixy.ccc.blocks[i].m_y;
            B_hoch = pixy.ccc.blocks[i].m_height;
            B_breit = pixy.ccc.blocks[i].m_width;
            B_Unterkante = unterkante;
            
            tmp = 2100.0/float(B_hoch); //Berechne Abstand 10 cm hoher Block nach Höhe in Pixeln
            B_Abstand = round(tmp);

          }

      }
    

    } //ende schleife über alle blöcke
  
  /*
    Serial.print("Block: ");
    Serial.println(B_ID); 
    Serial.print("Block_x: ");
    Serial.println(B_x); 
    Serial.print("Block_u: ");
    Serial.println(B_Unterkante); 
*/

 }
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
 void loop() 
 {

  int zufall;
  // Prüfe Hindernisse
  Finde_Block();
  Abstand = SpaceUS_V();
  
  // zeige gefunden Block an 
  if (B_ID == 1)
  {
	 lcd.setRGB(255,0,0);
  }
  else if (B_ID == 2)
  {
	  lcd.setRGB(0,255,0);
  }
  else
  {
	  lcd.setRGB(255,255,255);
  }

   // rot: prüfe, ob ausweichen rechts
  if ((B_ID == 1) && (B_x > 80) && (B_Unterkante > 120))
  {

	  Ausweichen_R();
  }

  else if ((B_ID == 2) && (B_x < 240) && (B_Unterkante > 120))
  {
	  //grün: ausweichen links
	  
      Ausweichen_L();
  }
  else // kein Block in Sicht, dem man ausweichen muss
  {
   
    Abstand = SpaceUS_V();	
    Abstand_L = SpaceUS_L();
    Abstand_R = SpaceUS_R();

    if (FR == 'K')
    {
        if (Abstand_L > 80)
        {
          FR = 'L';
        }
        else if (Abstand_R > 80)
        {
          FR = 'R';
        }
    }
	
    if ((Abstand < 30) && (millis() - MKurve > ZKurve)) // Nähe Wand gegenüber
    {
      
      stopMotor();
      
        
       if (FR == 'K')
       {
        Abstand_L = SpaceUS_L();
        Abstand_R = SpaceUS_R();
        if (Abstand_L > 60)
        {
          FR = 'L';
        }
        else if (Abstand_R > 60)
        {
          FR = 'R';
        }
        else
        {
      
            // wenn FR immer noch unklar, per Zufall auswählen
            zufall = random(2);
            if (zufall == 0)
            {
              FR = 'R';
            }
            else
            {
              FR = 'L';
            }
        }
      }

      lcd.setCursor(0,0);
      lcd.print(FR);
      delay(500);
      // prüfen: wenden oder Kurve
      if (FR == 'R')
      {
        Abstand_L = SpaceUS_L();
        if (Abstand_L > 35)
        {
          wenden_R();
        }
        else
        {
          // zuruck und Kurve
          runMotor_R(180);
          while (Abstand < 70) 
          {
            delay(20);
            Abstand = SpaceUS_V();
          }
          stopMotor();
          Kurve_R_MH();
          
        }
      }
      else // FR == L
      {
        
        Abstand_R = SpaceUS_R();
        if (Abstand_R > 35)
        {
          wenden_L();
        }
        else
        {
          // zuruck und Kurve
          runMotor_R(180);
          while (Abstand < 70) 
          {
            delay(20);
            Abstand = SpaceUS_V();
          }
          stopMotor();
          Kurve_L_MH();
        }
        stopMotor();
        lcd.setRGB(255,255,255);  //Ende Kurve, Wenden
        delay(500);
        runMotor(LangG);
      }
    }
    else
    { 
      // an der Außenwand orientieren
      Abstand_L = SpaceUS_L();
      Abstand_R = SpaceUS_R();
      if (FR == 'R')
      {
        Ausrichten_L();
      }
      else if (FR == 'L')
      {
        Ausrichten_R();
      }
  
      delay(20);
    }
     
  } // Ende kein Block zum Ausweichen in Sicht



/*
  
  //prüfen ob L abbiegen
  if((FR == 'L') && (Abstand_L > 80) && (millis() - MKurve > ZKurve))
  {
    Kurve_L_MH();

  }


    //prüfen ob R abbiegen
  if((FR == 'R') && (Abstand_R >80) && (millis() - MKurve > ZKurve))
  {
    Kurve_R_MH();
  }

*/
/*
  //alle ecken prüfen
  if(ecken == 12)
  {
    delay(100);
    PRGstopp();
  }

*/

}

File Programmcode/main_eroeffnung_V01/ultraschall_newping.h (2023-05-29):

//ultaschall mit newping librarie (experiemtiert)

//newping librarie
#include <NewPing.h>
#include <RunningMedian.h>

// Definition der pins

//Vorderer sensor
#define TRIG_PIN_V  8
#define ECHO_PIN_V  9
#define BAUD_RATE  9600

//Linker Sensor
#define TRIG_PIN_L  A0
#define ECHO_PIN_L  A1

//Rechter Sensor
#define TRIG_PIN_R  A2
#define ECHO_PIN_R  A3

#define MAX_DISTANCE 200
#define ITERATIONS   3

NewPing US_V(TRIG_PIN_V, ECHO_PIN_V, MAX_DISTANCE);
NewPing US_L(TRIG_PIN_L, ECHO_PIN_L, MAX_DISTANCE);
NewPing US_R(TRIG_PIN_R, ECHO_PIN_R, MAX_DISTANCE);


//US eigene function Vorne
int SpaceUS_V()
{

  distance = US_V.ping_median(ITERATIONS MAX_DISTANCE);

   return distance;
}

//US eigene function Rechts
int SpaceUS_R()
{

  distance = US_R.ping_median(ITERATIONS MAX_DISTANCE);
  
   return distance;

}

//US eigene function Links
int SpaceUS_L()
{
  distance = US_L.ping_median(ITERATIONS MAX_DISTANCE);
   
   return distance;

}

void ultraschallstart()
{
// Initialisierung der US Pins Vorne
  pinMode(TRIG_PIN_V, OUTPUT);
  pinMode(ECHO_PIN_V, INPUT);

  // Initialisierung der US Pins Links
  pinMode(TRIG_PIN_L, OUTPUT);
  pinMode(ECHO_PIN_L, INPUT);

  // Initialisierung der US Pins Rechts
  pinMode(TRIG_PIN_R, OUTPUT);
  pinMode(ECHO_PIN_R, INPUT);
}

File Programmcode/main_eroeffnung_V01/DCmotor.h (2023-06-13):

// Gleichstrommotor 1
int GSM1 = 5;
int in1 = 6;
int in2 = 7; 

// rückwärts
 void runMotor_R(int Speed) 
 {
  int tmpSpeed;
  digitalWrite(in1, LOW);  
  digitalWrite(in2, HIGH);
  if(Speed < 185)
  {
    tmpSpeed = 185;
    analogWrite(GSM1, Speed);
    delay(100);
  }
  analogWrite(GSM1, Speed);  
 }


 // Stoppen
 void stopMotor() 
 {
  digitalWrite(in1, LOW);  
  digitalWrite(in2, LOW);
  analogWrite(GSM1, 0); 
  //aktives bremsen durch kurzes rückwärts fahren
  digitalWrite(in1, LOW);  
  digitalWrite(in2, HIGH);
  analogWrite(GSM1, 185);
  delay(50); 
  digitalWrite(in1, LOW);  
  digitalWrite(in2, LOW);
  analogWrite(GSM1, 0); 
 }



 //motor run
 void runMotor(int Speed)  
 {
  int tmpSpeed;
  digitalWrite(in1, HIGH);  // Motor 1 beginnt zu rotieren
  digitalWrite(in2, LOW);
  if(Speed < 185)
  {
    tmpSpeed = 185;
    analogWrite(GSM1, Speed);   // Motor 1 soll mit der Geschwindigkeit "200" (max. 255) rotieren
    delay(100);
  }
  analogWrite(GSM1, Speed);

 }



//Stop programm
void PRGstopp() 
{
  unsigned long FZ;  
    digitalWrite(in1, LOW);
    digitalWrite(in2, LOW);
    analogWrite(GSM1, 0);
  // Speichere die aktuelle Zeit
  FZ = millis() - start_time;
    lcd.clear();
    lcd.setCursor(0, 0);
    lcd.print("zeit: ");
    lcd.print(FZ);
    delay(9999999);

}



void motorsetup()
{
//pinmodes motor
  pinMode(GSM1, OUTPUT);    
  pinMode(in1, OUTPUT);
  pinMode(in2, OUTPUT);
}

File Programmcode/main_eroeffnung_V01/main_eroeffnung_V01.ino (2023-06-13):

//hauptprogramm ohne Hindernisse 01

//Belegung der Pins
//button = 4
//kamera = 10-13
//Ultraschall = 5-6
//I2C Bus = A4-A5
//MotorSpeed = 9
//Motorichtung = 7-8
//Abstandsmesser = A0-A1
//Servo Lenkung = 3
//frei = A2-A3

///////////////////////////////////////////////////////////////
/*

██╗     ██╗██████╗ ██████╗  █████╗ ██████╗ ██╗███████╗███████╗
██║     ██║██╔══██╗██╔══██╗██╔══██╗██╔══██╗██║██╔════╝██╔════╝
██║     ██║██████╔╝██████╔╝███████║██████╔╝██║█████╗  ███████╗
██║     ██║██╔══██╗██╔══██╗██╔══██║██╔══██╗██║██╔══╝  ╚════██║
███████╗██║██████╔╝██║  ██║██║  ██║██║  ██║██║███████╗███████║
╚══════╝╚═╝╚═════╝ ╚═╝  ╚═╝╚═╝  ╚═╝╚═╝  ╚═╝╚═╝╚══════╝╚══════╝
                                                              
*/
///////////////////////////////////////////////////////////////


//--------------------------------------------

//Servo Abteilung libraries
#include <Servo.h>
//-------------------------------------------------

//libraries rgb
#include <Wire.h>
#include "rgb_lcd.h"

//--------------------------------------------------

#include <NewPing.h>




/////////////////////////////////////////////////////////////////////////////////////////////////////////////////////////////////////
/*       
██████╗ ██╗      ██████╗ ██████╗  █████╗ ██╗     ███████╗    ██╗   ██╗ █████╗ ██████╗ ██╗ █████╗ ██████╗ ██╗     ███████╗███╗   ██╗
██╔════╝ ██║     ██╔═══██╗██╔══██╗██╔══██╗██║     ██╔════╝    ██║   ██║██╔══██╗██╔══██╗██║██╔══██╗██╔══██╗██║     ██╔════╝████╗  ██║
██║  ███╗██║     ██║   ██║██████╔╝███████║██║     █████╗      ██║   ██║███████║██████╔╝██║███████║██████╔╝██║     █████╗  ██╔██╗ ██║
██║   ██║██║     ██║   ██║██╔══██╗██╔══██║██║     ██╔══╝      ╚██╗ ██╔╝██╔══██║██╔══██╗██║██╔══██║██╔══██╗██║     ██╔══╝  ██║╚██╗██║
╚██████╔╝███████╗╚██████╔╝██████╔╝██║  ██║███████╗███████╗     ╚████╔╝ ██║  ██║██║  ██║██║██║  ██║██████╔╝███████╗███████╗██║ ╚████║
 ╚═════╝ ╚══════╝ ╚═════╝ ╚═════╝ ╚═╝  ╚═╝╚══════╝╚══════╝      ╚═══╝  ╚═╝  ╚═╝╚═╝  ╚═╝╚═╝╚═╝  ╚═╝╚═════╝ ╚══════╝╚══════╝╚═╝  ╚═══╝
*/                                                                                                                               
/////////////////////////////////////////////////////////////////////////////////////////////////////////////////////////////////////


//timer
unsigned long start_time;
//--------------------------------------------------

 //geschwindigkeiten
  int NormG =  200;
  int LangG =  180;
  int KurvG =  220; 
  int StartG = 150;


//LCD anschluss
 int Button = 4;
 int colorR = 255;
 int colorG = 0;
 int colorB = 0;
 //LCD screen selbst
 rgb_lcd lcd;

//runden/ecken zähler
int ecken = 0;
int runden = 0; 
int quadrant = 0;

//Abstands eigene  funktionen (messwerte)
 int Abstand;
 int Abstand_L;
 int Abstand_R;
 
 float winkel;
 float gefahr;
 float korrektur_L = -35.0;
 float korrektur_R = 20.0;
 
  //Fahrtrichtung
  char FR = 'K';

  //hindernisse
  char Block = 'K';

 //letzte kurve messen
 unsigned long MKurve;
 unsigned long ZKurve = 1000;
  
  //beide ausrichtungen (L/R)
  int Wandabstand = 25;

  
//eigene Module
#include "DCmotor.h"
#include "gyro.h"
#include "lenkung.h"
#include "ultraschall.h"

////////////////////////////////////////////////////////////////////////////////////////////////////////////////////////////////////////
/*
    
███████╗██╗ ██████╗ ███████╗███╗   ██╗███████╗    ███████╗██╗   ██╗███╗   ██╗██╗  ██╗████████╗██╗ ██████╗ ███╗   ██╗███████╗███╗   ██╗
██╔════╝██║██╔════╝ ██╔════╝████╗  ██║██╔════╝    ██╔════╝██║   ██║████╗  ██║██║ ██╔╝╚══██╔══╝██║██╔═══██╗████╗  ██║██╔════╝████╗  ██║
█████╗  ██║██║  ███╗█████╗  ██╔██╗ ██║█████╗      █████╗  ██║   ██║██╔██╗ ██║█████╔╝    ██║   ██║██║   ██║██╔██╗ ██║█████╗  ██╔██╗ ██║
██╔══╝  ██║██║   ██║██╔══╝  ██║╚██╗██║██╔══╝      ██╔══╝  ██║   ██║██║╚██╗██║██╔═██╗    ██║   ██║██║   ██║██║╚██╗██║██╔══╝  ██║╚██╗██║
███████╗██║╚██████╔╝███████╗██║ ╚████║███████╗    ██║     ╚██████╔╝██║ ╚████║██║  ██╗   ██║   ██║╚██████╔╝██║ ╚████║███████╗██║ ╚████║
╚══════╝╚═╝ ╚═════╝ ╚══════╝╚═╝  ╚═══╝╚══════╝    ╚═╝      ╚═════╝ ╚═╝  ╚═══╝╚═╝  ╚═╝   ╚═╝   ╚═╝ ╚═════╝ ╚═╝  ╚═══╝╚══════╝╚═╝  ╚═══╝
*/
/////////////////////////////////////////////////////////////////////////////////////////////////////////////////////////////////////////
 

  //ausrichten
  void Ausrichten()
  {
    int Lenkung;
    Lenkung = (Abstand_L - Abstand_R)*0.3;
    if (Lenkung > 30.0)
    {
      Lenkung = 30;
    }
    else if (Lenkung < -30.0)
    {
      Lenkung = -30;
    }

    if(Lenkung < 0)
    {
      Lenkung = Lenkung *(-1);
      rechts(Lenkung);
    }
    
    else
    {
      links(Lenkung);
    }

    delay(20);

  }

   //ausrichten
  void Ausrichten_L()
  {
    int Lenkung;
    Lenkung = (Abstand_L - Wandabstand)*0.9;
    if (Lenkung > 30.0)
    {
      Lenkung = 30;
    }
    else if (Lenkung < -30.0)
    {
      Lenkung = -30;
    }


    if(Lenkung < 0)
    {
      Lenkung = Lenkung *(-1);
      rechts(Lenkung);
      lcd.setCursor(0, 1);
      lcd.print("R ");
      lcd.print(Lenkung);
    }
    
    else
    {
      links(Lenkung);
      lcd.setCursor(0, 1);
      lcd.print("L ");
      lcd.print(Lenkung);
    }

    delay(50);

  }

   //ausrichten
  void Ausrichten_R()
  {
    int Lenkung;
    Lenkung = (Wandabstand - Abstand_R)*0.9;
    if (Lenkung > 30.0)
    {
      Lenkung = 30;
    }
    else if (Lenkung < -30.0)
    {
      Lenkung = -30;
    }


    if(Lenkung < 0)
    {
      Lenkung = Lenkung *(-1);
      rechts(Lenkung);
      lcd.setCursor(0, 1);
      lcd.print("R ");
      lcd.print(Lenkung);
    }
    
    else
    {
      links(Lenkung);
      lcd.setCursor(0, 1);
      lcd.print("L ");
      lcd.print(Lenkung);
    }

    delay(50);

  }

  void Kurve_L()
  {
         int Speed;
         float ZW;
         Speed = LangG;
        links(40);
        lcd.setRGB(0, 0, 255);
        winkel = IMU_getAngle();
        if(quadrant == 0)
        {
          ZW = 270.0;
        }
        else if(quadrant == 1)
        {
          ZW = 180.0;
        }
        else if(quadrant == 2)
        {
          ZW = 90.0;
        }
        else if(quadrant == 3)
        {
          ZW = 0.0;
        }
        runMotor(LangG);               
        while(winkel > ZW - korrektur_L)
        {
           
           winkel = IMU_getAngle();
            Speed = Speed + 5;
            if (Speed > KurvG)
            {
              Speed = KurvG;
            }
              runMotor(Speed);
              delay(50);
        }
      ecken = ecken + 1;
      mitte();
    runMotor(NormG);
    Abstand_L = SpaceUS_L;
    while(Abstand_L > 60)
    {
      Abstand_L = SpaceUS_L();
      
      winkel = IMU_getAngle();

      delay(10);
    }
    lcd.setRGB(0, 255, 0);
    MKurve = millis();
  }
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

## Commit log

2023-04-29 Ultra schall tests
    diese programme haben die ultraschall sensoren getestet bei Fehlern.
2023-04-29 Eröffnungsvideo
    eine beschreibung wie der Roboter beim eröffnungsrennen fährt. Mit dem youtube link
2023-05-12 Backup Codes
    Dieser Ordner beinhaltet unsere Backup codes welche wir im Verlauf der Hauptprogramm Editierung ausgeschnitten haben.
2023-05-12 Backup Codes
    Diese Codes haben sich im Verlauf der Code Editierung als vorübergehend überschüssig ergeben. Ein Backup der Codes wurde immer gesichert
2023-05-29 alte_versionen Ordner
    alle Programmcodes des vorherigen Wettbewerbs wurden in den [`alte_versionen`](https://github.com/biswro2023/smartiecar/tree/master/Programmcode) Ordner verschoben.
2023-05-29 main_hinderniss_V01
    Eine Prototypen Version von dem Hindernissrennen Programm, aufgeteilt und aufgeräumt in die einzelnen Funktionen
2023-05-29 eröfnungrennen Update
    Fehler beim abbiegen in einer engen Straße durch berührung der gegenüberliegenden Wand. Schlussendlich musste das Auto nur langsamer abbiegen, denn das Auto berührt nicht die Wand beim langsamen Fahr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
2023-05-29 eröfnungrennen Update
    dateien wurden beim vorherigen commit nicht upgeloaded.
    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
2023-05-30 alte versionen update
    die einzelnen ultraschall tests in einen ordner zusammen gelegt
2023-06-13 hinderniss und eroeffnung update
    Hindernissrennen: runMotor_R() Funktion angewendet um vor einer Wand gegen zu bremsen und zurücksetzten wenn eine wand zu nahe ist.
    Eroeffnungsrennen: neue Ausrichtung des int mittig.
    Für beide Programme wurde die Datei Farbe.h gelöscht und jegliche Funktionen aus den .ino Dateien entfernt. Grund dafür ist dass wir den Farbsensor nicht mehr benutzen.
2023-06-13 update Dateien
    Neue Dateinamen ersetzen die alten
2023-06-15 Update README.md
    Erweiterungen des ursprünglichen ReadMEs:
    defekter Servo
    neue Sensorenhlaterung
    neues Getriebe
2023-06-15 readme.md update
    die Texte angepasst
2023-06-15 Add files via upload
    Neu Bilder von allen Seiten des Autos
2023-06-15 Update README.md
    Beschriftung Bild :
    Kaputter Servo
2023-06-15 Unser Team
    Eine kurze Beschreibung unseres Teams sowie ein Bild von der ersten Version unseres Roboters.
2023-06-15 README.md Update
    Beschreibung zu dem hindernissrennen Hinzugefügt.
    Funktionen dazugeschrieben und ` ` genutzt um diese zu markieren
2023-06-15 Update README.md
    Neue Einletung und verzeichnisse geschrieben
2023-06-15 Update README.md
    Erweiterung des bisherigen Textes mit Korrekturen
